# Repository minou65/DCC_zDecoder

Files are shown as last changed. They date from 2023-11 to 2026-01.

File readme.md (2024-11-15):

# DCC zDecoder

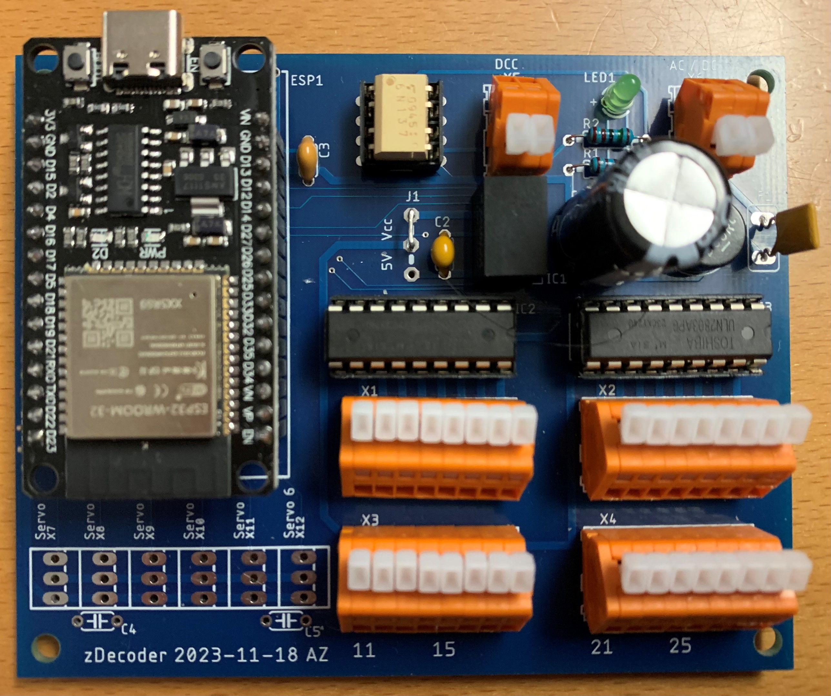
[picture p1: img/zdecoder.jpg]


- [DCC zDecoder](#dcc-zdecoder)
	- [Beschreibung](#beschreibung)
	- [Platinen](#platinen)
	- [Librarys](#librarys)
	- [Pin mapping](#pin-mapping)
	- [Betriebsarten](#betriebsarten)
		- [in Vorbereitung](#in-vorbereitung)
	- [Schema](#schema)
	- [Materialliste](#materialliste)
	- [Anschlüsse](#anschlüsse)
	- [Inbetriebnahme](#inbetriebnahme)
	- [Web UI](#web-ui)
		- [Overview](#overview)
		- [Groups](#groups)
		- [Config](#config)
	- [WiFi](#wifi)
		- [Default Password](#default-password)
		- [Default IP address](#default-ip-address)
		- [OTA](#ota)
		- [Configuration options](#configuration-options)
		- [Blinking codes](#blinking-codes)
	- [Firmware](#firmware)
	- [Reset](#reset)

## Beschreibung
Das ist ein NRMA DCC dekoder basirend auf einem ESP32 NodeMCU. 
- Er kann bis zu 16 Ausgänge ansteuern. 
- Stellt eine Wifi AP zur verfügung oder kann in Wifi Netz integriert werden
- Wird via Web UI konfiguriert
- Kann via DCC oder Web UI gesteuert werden

Der Decoder kann an einer Spannung von 8 - 28V DC oder 18 - 36V AC betrieben werden. Pro Ausgang 
kann eine Last von 500mA geschaltet werden. Ist J1 auf der Stellung 5V, darf der gesamt Strom 1A
nicht übersteigen.

[Top of document](#dcc-zdecoder)

## Platinen
Unbestückte Platinen sind bei mir erhältlich für CHF 5.00 / Stück plus Porto. Bestückte Platinen CHF 30.00 plus Porto
[Top of document](#dcc-zdecoder)

## Librarys
Die folgenden Bibliotheken werden verwendet und müssen installiert werden
- [NMRA DCC](https://github.com/mrrwa/NmraDcc)
- [IotWebConf (3.2.3)](https://github.com/minou65/IotWebConf)
- [IotWebRoot](https://github.com/minou65/IotWebRoot)

[Top of document](#dcc-zdecoder)

## Pin mapping
In der Header datei [pinmapping.h](src/pinmapping.h) können die Pins für die 16 Ausgänge an die eigenen Bedürfnisse angepasst werden.

```cpp
static uint8_t ChannelToGPIOMapping[16] = {
	GPIO_NUM_23, // O11
	GPIO_NUM_22, // O12
	GPIO_NUM_21, // O13
	GPIO_NUM_19, // O14
	GPIO_NUM_18, // O15
	GPIO_NUM_17, // O16
	GPIO_NUM_16, // O17
	GPIO_NUM_4,  // O18

	GPIO_NUM_33, // O21
	GPIO_NUM_32, // O22
	GPIO_NUM_25, // O23
	GPIO_NUM_26, // O24
	GPIO_NUM_27, // O25
	GPIO_NUM_14, // O26
	GPIO_NUM_12, // O27
	GPIO_NUM_13  // O28

};
```
[Top of document](#dcc-zdecoder)

## Betriebsarten

Der zDecoder untersützt folgende Betriebsarten
- [Watchdog](doc/watchdog.md#watchdog-1)
- [einfacher Ausgang](doc/blinkers.md#einfacher-ausgang)
- [Blinker](doc/blinkers.md#blinker)
- [Wechselblinker](doc/blinkers.md#wechselblinker)
- [Fernseher](doc/blinkers.md#fernseher)
- [Schweisslicht](doc/blinkers.md#schweissen)
- [Feuer](doc/blinkers.md#feuer)
- [Blitzlicht](doc/blinkers.md#blitzlicht)
- [Lauflicht 1](doc/blinkers.md#lauflicht-1)
- [Lauflicht 2](doc/blinkers.md#lauflicht-2)
- [Lauflicht 3](doc/blinkers.md#lauflicht-3)
- [Lauflicht 4](doc/blinkers.md#lauflicht-4)
- [Hausbeleuchtung](doc/blinkers.md#hausbeleuchtung)
- [Neonlampen](doc/blinkers.md#neon-lampe)
- [Natriumlampen](doc/blinkers.md#natrium-lampe)
- [Entkuppler](doc/coils.md#entkuppler)
- [Weiche](doc/coils.md#weiche)
- [Servo](doc/servo.md#servo-1)

[Top of document](#dcc-zdecoder)

### in Vorbereitung
- SBB Hauptsignal 2 flammig
- SBB Hauptsignal 3 flammig
- SBB Hauptsignal 4 flammig
- SBB Hauptsignal 5 flammig
- SBB Zwergsignal
- Strassensignal

[Top of document](#dcc-zdecoder)

## Schema
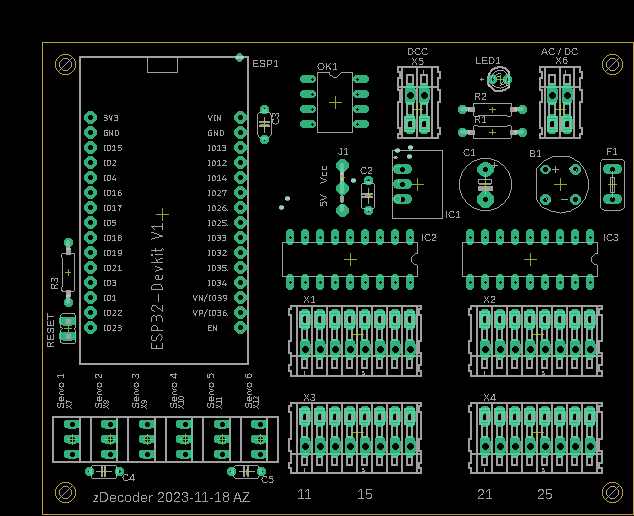
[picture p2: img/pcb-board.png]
PCB Board


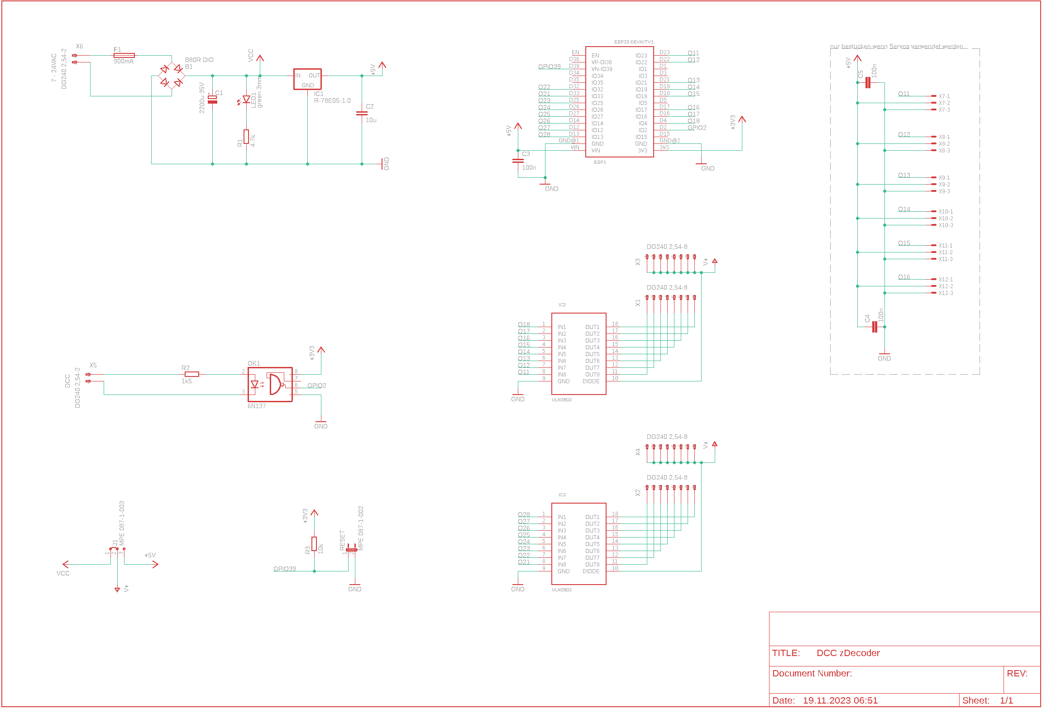
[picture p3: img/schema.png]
Schema


## Materialliste

[Partliste](sch/partlist.txt)

[Top of document](#dcc-zdecoder)

## Anschlüsse

| Klemmenblock | Beschreibung |
| --- | --- |
| X1 - X2 | + Anschluss für Verbraucher 5/12-28VDc, je nach position von J1 |
| X3 - X4 | - Anschluss für Verbraucher |
| X5 | DCC signal |
| X6 | Anschluss versorgungspannung für Decoder und Verbraucher. 12 - 28VDC/AC |
| X7 - X12 | Anschluss für Servos |

[Top of document](#dcc-zdecoder)

## Inbetriebnahme

Nachdem alles zusammengebaut ist und alle Lötstellen sorgfältig überprüft wurden, kann das Program auf den ESP aufgespielt werden.
Lauflicht 2

[Top of document](#dcc-zdecoder)

## Web UI

Mittels des Web User interfaces kann der zDecoder einfach konfiguriert und bedient werden

### Overview

auf dieser Seite sind alle wichtigen Informationn zu zDecoder ersichtlich

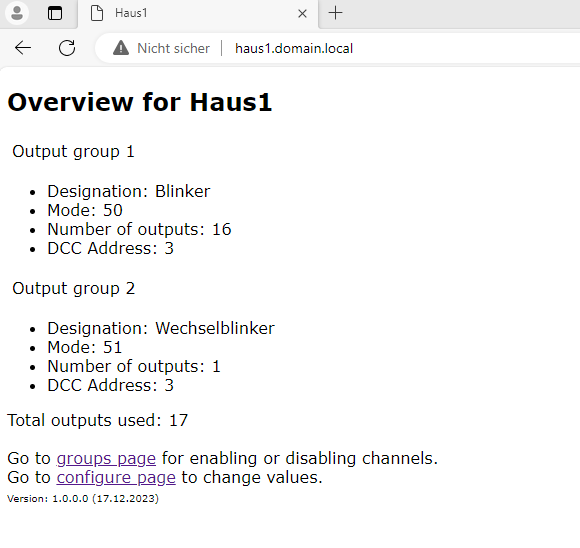
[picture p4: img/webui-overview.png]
Overview


[Top of document](#dcc-zdecoder)

### Groups

auf dieser Seite können die Gruppen ein und ausgescahltet werden. Wird über DCC geschaltet, ist auf dieser Seite auch der jeweilige Status ersichtlich. Rot ist ausgeschaltet, grün ist eingeschaltet

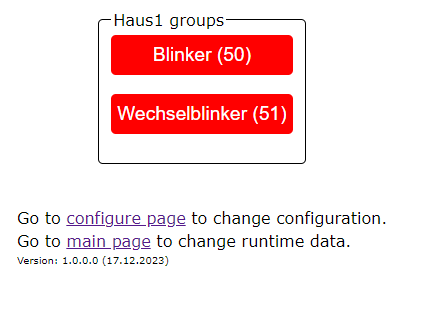
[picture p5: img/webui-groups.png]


[Top of document](#dcc-zdecoder)

### Config

auf dieser Seite können die Gruppen erstellt und konfiguriert werden. Die Bedeutung und Verwendung der Parameter ist beim jeweiligen Objekt unter [Betriebsarten](#betriebsarten) beschrieben.

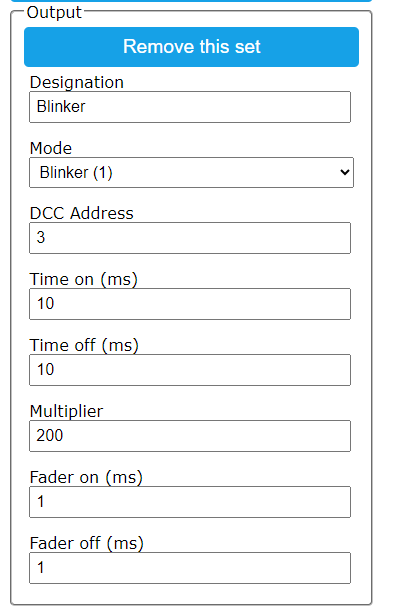
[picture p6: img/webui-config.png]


[Top of document](#dcc-zdecoder)

## WiFi

### Default Password

Wenn nicht mit einem AP verbunden, ist das Standardpasswort 123456789

[Top of document](#dcc-zdecoder)

### Default IP address

Wenn nicht mit einem AP verbunden, ist die IP Adresse 192.168.4.1

[Top of document](#dcc-zdecoder)

### OTA 
OTA ist aktiviert und kann verwenbdet werden. Damit ist es möglich, die Software des zDecoders zu updaten ohne unter die Anlage krichen zu müssen. Die IP Adresse ist entweder die Default IP address oder die vom AP zugewissene. Port ist Standart

[Top of document](#dcc-zdecoder)

### Configuration options
Nach dem ersten Start müssen einige Werte eingerichtet werden.

| Parameter | Beschreibung |
|---|---|
| Thing name | Name des Decoders. Es sollten keine Sonderzeichen und <br> Umlaute verwendet werden. Punkte und Leerzeichen sollten <br> ebenfalls nicht verwendet werden.
| AP password | Dieses Passwort wird verwendet, wenn Sie später auf <br> das Gerät zugreifen möchten. Sie müssen ein Passwort <br> mit mindestens 8, höchstens 32 Zeichen verwenden. <br> Es steht Ihnen frei, beliebige Zeichen zu verwenden, <br> Es sollte ein Passwort mit mindestens 12 Zeichen Länge gewählt werden. |
| WiFi SSID | Name des WLan mit welchem das thing verwendet werden soll. |
| WiFi password | Das Passwort zum Netzwerk, mit welchem das Thing verbunden werden soll. |

[Top of document](#dcc-zdecoder)

### Blinking codes

In der nachfolgenden Tabelle fasst die verschiedenen Blinkcodes zusammen

| Code | Bedeutung |
|---|---|
| rasches blinken | meisten ein, unterbrochen durch kurze aus perioden. <br> Eigener AP ist aktiviert und sie können mit <br> dem Smartphone oder einem Computer eine<br> Verbindung zum Thing herstellen. |
| wechsel blinken | Das Thing versucht mit einem AP zu verbinden |
| langsames blinken | meistens aus mit kurzem blinken <br> Das Thing ist online und mit dem WLan verbunden |

[Top of document](#dcc-zdecoder)

## Firmware
Hier kann, eine entsprechende Datei vorausgesetzt, die Firmware des decoders aktualisiert werden

## Reset
Wurde das Passwort vergessen oder funktioniert der Decoder nicht mehr kann durch schliessen des Jumpers Reset während dem booten, der Decoder auf die Werkseinstellungen zurückgesetzt werden.

[Top of document](#dcc-zdecoder)

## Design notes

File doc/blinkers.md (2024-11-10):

# Blinkers

## Inhalt
- [Blinkers](#blinkers)
  - [Inhalt](#inhalt)
  - [einfacher Ausgang](#einfacher-ausgang)
  - [Blinker](#blinker)
  - [Wechselblinker](#wechselblinker)
  - [Fernseher](#fernseher)
  - [Schweissen](#schweissen)
  - [Feuer](#feuer)
  - [Blitzlicht](#blitzlicht)
  - [Lauflicht 1](#lauflicht-1)
  - [Lauflicht 2](#lauflicht-2)
  - [Lauflicht 3](#lauflicht-3)
  - [Lauflicht 4](#lauflicht-4)
  - [Hausbeleuchtung](#hausbeleuchtung)
  - [Natrium Lampe](#natrium-lampe)
  - [Neon Lampe](#neon-lampe)

## einfacher Ausgang
Ein einfacher Ausgang um z.B. eine Lampe oder Relais ein und auszuschalten.

| Channel | Led Farbe | 
|:-:|---|
| 1 | n.a.  |

| Feld | Beschreibung | Wert |
| --- | --- | --- |
| Designation | Beschreibung des Channels | |
| Modus | ein/aus | einfacher Ausgang |
| Address | DCC Adresse des Ausgangs | default 3 |
| Brightness | Helligkeit des Ausgangs | default 255 |

[Betriebsarten](../readme.md#betriebsarten) <br>
[Top of document](#blinkers)

## Blinker
Einfacher blinker, welcher es erlaubt auch ein und aus zu faden

| Channel | Led Farbe |
|:-:|---|
| 1 | n.a.  |
| 2  | n.a. |

| Feld | Beschreibung | Wert |
| --- | --- | --- |
| Designation | | |
| Modus | | Blinker |
| Address | DCC Adresse des Ausgangs | default 3 |
| Blinker time on | ein in ms | |
| Blinker time off | aus in ms | |
| Multiplikator | Multiplikator mit welchem die ein / aus Zeit multipliziert wird | |
| Fade Time on | Zeit in ms für das Fade on | |
| Fade Time off | Zeit in ms für das Fade off | |
| Brightness | Helligkeit des Ausgangs | default 255 |

[Betriebsarten](../readme.md#betriebsarten) <br>
[Top of document](#blinkers)

## Wechselblinker
Wechselblinker, welcher es erlaubt auch ein und aus zu faden

| Channel | Led Farbe |
|:-:|---|
| 1 | n.a.  |
| 2  | n.a. |

| Feld | Beschreibung | Wert |
| --- | --- | --- |
| Designation | | |
| Modus | | Wechselblinker |
| Address | DCC Adresse des Ausgangs | default 3 |
| Blinker time on | ein in ms | |
| Blinker time off | aus in ms | |
| Multiplikator | Multiplikator mit welchem die ein / aus Zeit multipliziert wird | |
| Fade Time on | Zeit in ms für das Fade on | |
| Fade Time off | Zeit in ms für das Fade off | |
| Brightness | Helligkeit des Ausgangs | default 255 |

[Betriebsarten](../readme.md#betriebsarten) <br>
[Top of document](#blinkers)

## Fernseher
Simulation eines Fernsehers

| Channel | Led Farbe |
|:-:|---|
| 1 | blau  |

| Feld | Beschreibung | Wert |
| --- | --- | --- |
| Designation | | |
| Modus | | Fernseher |
| Address | DCC Adresse des Ausgangs | default 3 |
| Brightness | Helligkeit des Ausgangs | default 255 |

[Betriebsarten](../readme.md#betriebsarten) <br>
[Top of document](#blinkers)

## Schweissen
Simuliert ein Schweisslicht

| Channel | Led Farbe |
|:-:|---|
| 1 | weiss  |
| 2  |blau|
| 3  |organge|

| Feld | Beschreibung | Wert |
| --- | --- | --- |
| Designation | | |
| Modus | | Schweissen |
| Address | DCC Adresse des Ausgangs | default 3 |
| Blinker time on | minimalae Pause in ms zwischen zwei Schweiss vorgängen | |
| Blinker time off | maximale Pause in ms zwischen zwei Scheiss vorgängen  | |
| Multitiplikator | Faktor mit welchem die ein / aus Zeit mulitpliziert wird| |
| Brightness | Helligkeit des Ausgangs | default 255 |

[Betriebsarten](../readme.md#betriebsarten) <br>
[Top of document](#blinkers)

## Feuer
Simuliert ein flackerndes Feuer

| Channel | Led Farbe |
|:-:|---|
| 1 | gelb |
| 2  | rot |
| 3  | gelb |

| Feld | Beschreibung | Wert |
| --- | --- | --- |
| Designation | | |
| Modus |  |  Feuer |
| Address | DCC Adresse des Ausgangs | default 3 |
| Brightness | Helligkeit des Ausgangs | default 255 |

[Betriebsarten](../readme.md#betriebsarten) <br>
[Top of document](#blinkers)

## Blitzlicht
Simuliert einen Fotoblitz. Es wird ein Blitzlicht gewitter erzeugt und dann jeweils zwischen 5 und 30 sekunden gewartet, bis das nächste Blitzlicht Gewitter erzeugt wird
Die flashtime sollte zwischen 100 und 300 ms sein, um gute Ergebinsse zu erreichen.

| Channel | Led Farbe |
|:-:|---|
| 1 | weiss |

| Feld | Beschreibung | Wert |
| --- | --- | --- |
| Designation | | |
| Modus |  |  Blitzlicht |
| Address | DCC Adresse des Ausgangs | default 3 |
| Minimum pause time | minimale pausenzeit in milisekunden <br> wird mulitpliziert mit Multiplier | 10 |
| Maximal pause time | maximale pausenzeit in milisekunden <br> wird mulitpliziert mit Multiplier | 30 |
| Multiplier | Faktor mit welchem die min / max Pausenzeit mulitpliziert wird| 10 |
| Minimum flash time | minimale pausenzeit in sekunden | 5 |
| Maximal flash time | maximale pausenzeit in sekunden | 30 |
| Brightness | Helligkeit des Ausgangs | default 255 |

[Betriebsarten](../readme.md#betriebsarten) <br>
[Top of document](#blinkers)

## Lauflicht 1
Kette durchgehen und notwendige LED einschalten, die anderen aussschalten

| Channel | Led Farbe |
|:-:|---|
| 1 - max | n.a. |

| Feld | Beschreibung | Wert |
| --- | --- | --- |
| Designation | | |
| Modus | | Lauflicht 1 |
| Number of outputs| 1 - 16 | |
| Address | DCC Adresse des Ausgangs | default 3 |
| Blinker time on | | |
| Blinker time off | | |
| Einheit | | |
| Brightness | Helligkeit des Ausgangs | default 255 |

[Betriebsarten](../readme.md#betriebsarten) <br>
[Top of document](#blinkers)

## Lauflicht 2
Alle Lampen werden nacheinander eingschaltet, am Schluss werden alle ausgeschaltet

| Channel | Led Farbe |
|:-:|---|
| 1 - max | n.a. |

| Feld | Beschreibung | Wert |
| --- | --- | --- |
| Designation | | |
| Modus | | Lauflicht 2 |
| Number of outputs| 1 - 16 | |
| Address | DCC Adresse des Ausgangs | default 3 |
| Blinker time on | | |
| Blinker time off | | |
| Einheit | | |
| Brightness | Helligkeit des Ausgangs | default 255 |

[Betriebsarten](../readme.md#betriebsarten) <br>
[Top of document](#blinkers)

## Lauflicht 3
Lampe für Lampe wird eingeschaltet. Sind alle eingeschaltet, wird mit der ersten Lampe begonnen zu löschen.

| Channel | Led Farbe |
|:-:|---|
| 1 - max | n.a. |

| Feld | Beschreibung | Wert |
| --- | --- | --- |
| Designation | | |
| Modus | | Lauflicht 3 |
| Number of outputs| 1 - 16 | |
| Address | DCC Adresse des Ausgangs | default 3 |
| Blinker time on | | |
| Blinker time off | | |
| Einheit | | |
| Brightness | Helligkeit des Ausgangs | default 255 |

[Betriebsarten](../readme.md#betriebsarten) <br>
[Top of document](#blinkers)

## Lauflicht 4
Funktion analaog Lauflicht 1, aber in beide richtungen (Knigth rider)

| Channel | Led Farbe |
|:-:|---|
| 1 - max | n.a. |

| Feld | Beschreibung | Wert |
| --- | --- | --- |
| Designation | | |
| Modus | | |
| Modus | | Lauflicht 4 |
| Number of outputs| 1 - 16 | |
| Address | DCC Adresse des Ausgangs | default 3 |
| Blinker time on | | |
| Blinker time off | | |
| Einheit | | |
| Brightness | Helligkeit des Ausgangs | default 255 |

[Betriebsarten](../readme.md#betriebsarten) <br>
[Top of document](#blinkers)

## Hausbeleuchtung

| Channel | Led Farbe |
|:-:|---|
| 1 - max | n.a. |

| Feld | Beschreibung | Wert |
| --- | --- | --- |
| Designation | | |
| Modus | | Hausbleuchtung |
| Number of outputs| 1 - 16 | |
| Address | DCC Adresse des Ausgangs | default 3 |
| Blinker time on | | |
| Blinker time off | | |
| Einheit | | |
| Brightness | Helligkeit des Ausgangs | default 255 |

[Betriebsarten](../readme.md#betriebsarten) <br>
[Top of document](#blinkers)

## Natrium Lampe
Simuliert eine oder mehere Natriumlampen. Beim einschalten beginnt die lampe zu glühen um dann den Betriebsdruck aufzubauen und voll zu leuchten. In dieser Zeit leuchtet die LED immer heller. Beim ausschalten glüht die Lampe aus um nach einer bestimmten Zeit komplett dunckel zu sein. Über die Zahl chance wird bestimmt ob es allenfalls ein defekte Lampe gibt. Es wird jweils gewürfelt, welche Lampe defekt ist.

| Channel | Led Farbe |
|:-:|---|
| 1 - max | gelb |

| Feld | Beschreibung | Wert |
| --- | --- | --- |
| Designation | | |
| Modus | | Natriumlampen |
| Number of outputs| 1 - 16 | |
| Address | DCC Adresse des Ausgangs | default 3 ||
| Mulitiplier | Prozentuale chance auf defekte Lampe: <br/> für 50:50 den Wert 1. <br/> für 33:66 den Wert 2, etc. <br/> wenn Null dann gibt es keine defekte Lampe <br/> wenn 255, dann gibt es immer eine defekte Lampe | |
| Fade Time on | minimale Zeit für Glühen| |
| Fade Time off | maximale Zeit für Glühen | |
| Brightness | Helligkeit des Ausgangs | default 255 |

[Betriebsarten](../readme.md#betriebsarten) <br>
[Top of document](#blinkers)

## Neon Lampe
Simuliert eine oder mehere Nenolampen. Beim einschalten blinken die Lampen 1-5 mal. Je nach Anzahl Lampen und einstellung der Chance kommt es immer mal vor das eis eine defekte Lampe gibt. Diese wird dann dauerhaft versuchen einzuschalten.

| Channel | Led Farbe |
|:-:|---|
| 1 - max | weiss |

| Feld | Beschreibung | Wert |
| --- | --- | --- |
| Designation | | |
| Modus | | Neonlampen |
| Number of outputs| 1 - 16 | |
| Address | DCC Adresse des Ausgangs | default 3 |
| Mulitiplier | Prozentuale chance auf defekte Lampe: <br/> für 50:50 den Wert 1. <br/> für 33:66 den Wert 2, etc. <br/> wenn Null dann gibt es keine defekte Lampe <br/> wenn 255, dann gibt es immer eine defekte Lampe | |
| Brightness | Helligkeit des Ausgangs | default 255 |

[Betriebsarten](../readme.md#betriebsarten) <br>
[Top of document](#blinkers)

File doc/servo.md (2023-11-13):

# Servo

- [Servo](#servo)
  - [Servo](#servo-1)

## Servo
Dies ist ein Servo Ausgang. Er wird mittels einer Weichenadresse angesteuert

| Feld | Beschreibung | Wert |
| --- | --- | --- |
| Designation | Beschreibung des Servos | |
| Address | DCC Adresse des Servos. | default 3 |
| Travel time | Zeit in ms die der Server verwendet um vom Limit 1 (2) nach Limit 2 (1) zu bewegen | default 10 |
| Multiplier | Multiplikator mit welchem die Zeit multipliziert wird | default 10 |
| Limit 1 | Limite 1 in °. Es können Werte zwischen 0 und 180 eingestellt werden | default 0 |
| Limit 2 | Limite 2 in °. Es können Werte zwischen 0 und 180 eingestellt werden | default 180 |

[Betriebsarten](../readme.md#betriebsarten) <br>
[Top of document](#servo)

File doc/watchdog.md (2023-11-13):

# Watchdog

## Inhalt

- [Watchdog](#watchdog)
  - [Inhalt](#inhalt)
  - [Watchdog](#watchdog-1)

## Watchdog
Mit dem Watchdog kann überprüft werden ob innheralb einer bestimmten Zeit DCC Signale empfangen werden

| Channel | Led Farbe | 
|:-:|---|
| 1 | keine  |

| Feld | Beschreibung | Wert |
| --- | --- | --- |
| Designation | Beschreibung des Channels | |
| Modus |  | einfacher Ausgang |
| Address | DCC Adresse des Ausgangs | default 3 |
| Blinker time on | Zeit in ms in der ein DCC Signal empfangen werden musss | |
| Multiplikator | Multiplikator mit welchem die ein Zeit multipliziert wird | |

[Betriebsarten](../readme.md#betriebsarten) <br>
[Top of document](#watchdog)

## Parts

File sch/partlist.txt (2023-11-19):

Partlist

Exported from DCC zDecoder.brd at 19.11.2023 06:50

EAGLE Version 9.6.2 Copyright (c) 1988-2020 Autodesk, Inc.

Assembly variant: 

Part     Value          Package        Library     Position (mm)         Orientation

B1       B80R DIO       RB1A           rectifier   (87.63 55.88)         R0
C1       2200u 35V      E5-8,5         rcl         (74.93 55.88)         R270
C2       10u            C050-024X044   rcl         (55.118 53.975)       R90
C3       100n           C050-024X044   rcl         (37.592 66.04)        R270
C4       100n           C050-024X044   rcl         (10.414 7.239)        R0
C5       100n           C050-024X044   rcl         (34.544 7.239)        R0
ESP1     ESP32DEVKITV1  ESP32-DEVKITV1 _esp32      (20.32 50.8)          R270
F1       900mA          TE5            fuse        (96.52 55.88)         R270
IC1      R-78E05-1.0    R-78E-XX1.0    _eigene     (63.5 55.88)          R270
IC2      ULN2803        DIL18          _eigene     (52.07 43.18)         R180
IC3      ULN2803        DIL18          _eigene     (82.55 43.18)         R180
J1       MPE 087-1-003  04C            jumper      (50.8 57.15)          R270
LED1     green 3mm      LED3MM         led         (77.47 73.66)         R0
OK1      6N137          DIL08          optocoupler (49.53 69.85)         R270
R1       4.7k           0207/10        rcl         (76.2 64.77)          R0
R2       1k5            0207/10        rcl         (76.2 68.58)          R0
R3       10k            0207/10        rcl         (4.318 41.021)        R90
RESET    MPE 087-1-002  JP1            jumper      (4.318 31.496)        R180
X1       DG240 2,54-8   233-508        con-wago255 (53.34 30.48)         R0
X2       DG240 2,54-8   233-508        con-wago255 (83.82 30.48)         R0
X3       DG240 2,54-8   233-508        con-wago255 (53.34 13.97)         R0
X4       DG240 2,54-8   233-508        con-wago255 (83.82 13.97)         R0
X5       DG240 2,54-2   233-202        con-wago255 (63.5 68.58)          R180
X6       DG240 2,54-2   233-202        con-wago255 (87.63 68.58)         R180
X7       PSS 254/3G     22-23-2031     con-molex   (5.08 12.7)           R270
X8       PSS 254/3G     22-23-2031     con-molex   (11.43 12.7)          R270
X9       PSS 254/3G     22-23-2031     con-molex   (17.78 12.7)          R270
X10      PSS 254/3G     22-23-2031     con-molex   (24.13 12.7)          R270
X11      PSS 254/3G     22-23-2031     con-molex   (30.48 12.7)          R270
X12      PSS 254/3G     22-23-2031     con-molex   (36.83 12.7)          R270

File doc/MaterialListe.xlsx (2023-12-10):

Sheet: Tabelle1
PCB |  | PCBParts | CHF 3.50 | Bei Bestellung von 20Stk
ESP1 | ESP32 NodeMCU | ebay | CHF 4.70
IC1 | 6N137 | ebay | CHF 0.15
IC2 | ULN2803 | ebay | CHF 0.40
IC3 | ULN2803 | ebay | CHF 0.40
IC4 | DC/DC Wandler TSR 1-2450 | Reichelt | CHF 5.20
R1 |  |  | CHF 0.05
R2 |  |  | CHF 0.05
C1 |  |  | CHF 1.00
LED1 |  |  | CHF 0.05
B1 | B80R DIO | Reichelt | CHF 0.30
J1 |  |  | CHF 0.10
X1 | DG240 2,54-8 | Reichelt | CHF 1.60
X2 | DG240 2,54-8 | Reichelt | CHF 1.60
X3 | DG240 2,54-8 | Reichelt | CHF 1.60
X4 | DG240 2,54-8 | Reichelt | CHF 1.60
X5 | DG240 2,54-2 | Reichelt | CHF 0.50
X6 | DG240 2,54-2 | Reichelt | CHF 0.50
IC Sockel | GS 8 | Reichelt | CHF 0.05
IC Sockel | GS 16 | Reichelt | CHF 0.10
IC Sockel | GS 16 | Reichelt | CHF 0.10
Buchsenleiste |  | Reichelt | CHF 2.00
 | Total |  | CHF 25.55
 | Preis pro Ausgang |  | CHF 1.60
 | ohne Servoausgänge bestückt

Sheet: Kosten
Bauteil | Bestellnummer | Lieferant
Printplatte |  | PCB | CHF 4.50
F1 | U90 XEAA | ebay | CHF 0.20
B1 | B80R DIO | reichelt | CHF 0.30
C1 | 2200u 35V | ebay | CHF 1.00
C2 | 10u MLCC | ebay | CHF 0.10
C3 | 100n MLCC | ebay | CHF 0.10
ESP1 | ESP32 NodeMCU | ebay | CHF 4.70
IC1 | TSR 1-2450 | reichelt | CHF 5.20
IC2 | ULN2803 | ebay | CHF 0.40
IC3 | ULN2803 | ebay | CHF 0.40
J1 | MPE 087-1-003 | ebay | CHF 0.10
LED1 | green 3mm | ebay | CHF 0.15
OK1 | 6N137 | ebay | CHF 0.30
R1 | 4.7k | ebay | CHF 0.10
R2 | 1k5 | ebay | CHF 0.10
R3 | 10k | ebay | CHF 0.10
RESET | MPE 087-1-002 | ebay | CHF 0.10
X1 | DG240 2,54-8 | reichelt | CHF 1.40
X2 | DG240 2,54-8 | reichelt | CHF 1.40
X3 | DG240 2,54-8 | reichelt | CHF 1.40
X4 | DG240 2,54-8 | reichelt | CHF 1.40
X5 | DG240 2,54-2 | reichelt | CHF 0.50
X6 | DG240 2,54-2 | reichelt | CHF 0.50
IC Sockel | GS 8 | Reichelt | CHF 0.05
IC Sockel | GS 18 | Reichelt | CHF 0.10
IC Sockel | GS 18 | Reichelt | CHF 0.10
Buchsenleiste |  | Reichelt | CHF 2.00
 |  |  | CHF 26.70

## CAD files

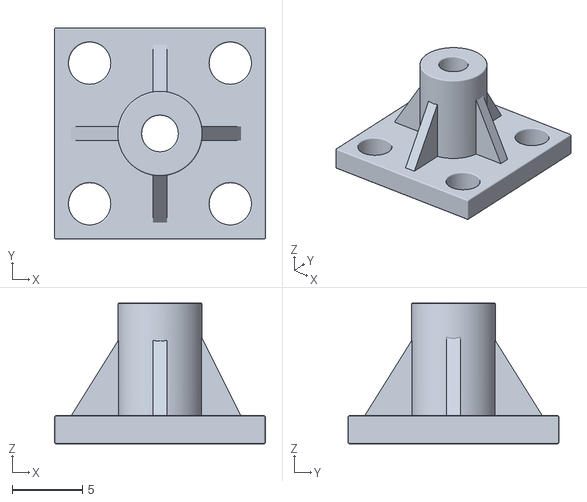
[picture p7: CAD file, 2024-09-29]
stl/PCB-Support.stl
15.0 x 15.0 x 10.0

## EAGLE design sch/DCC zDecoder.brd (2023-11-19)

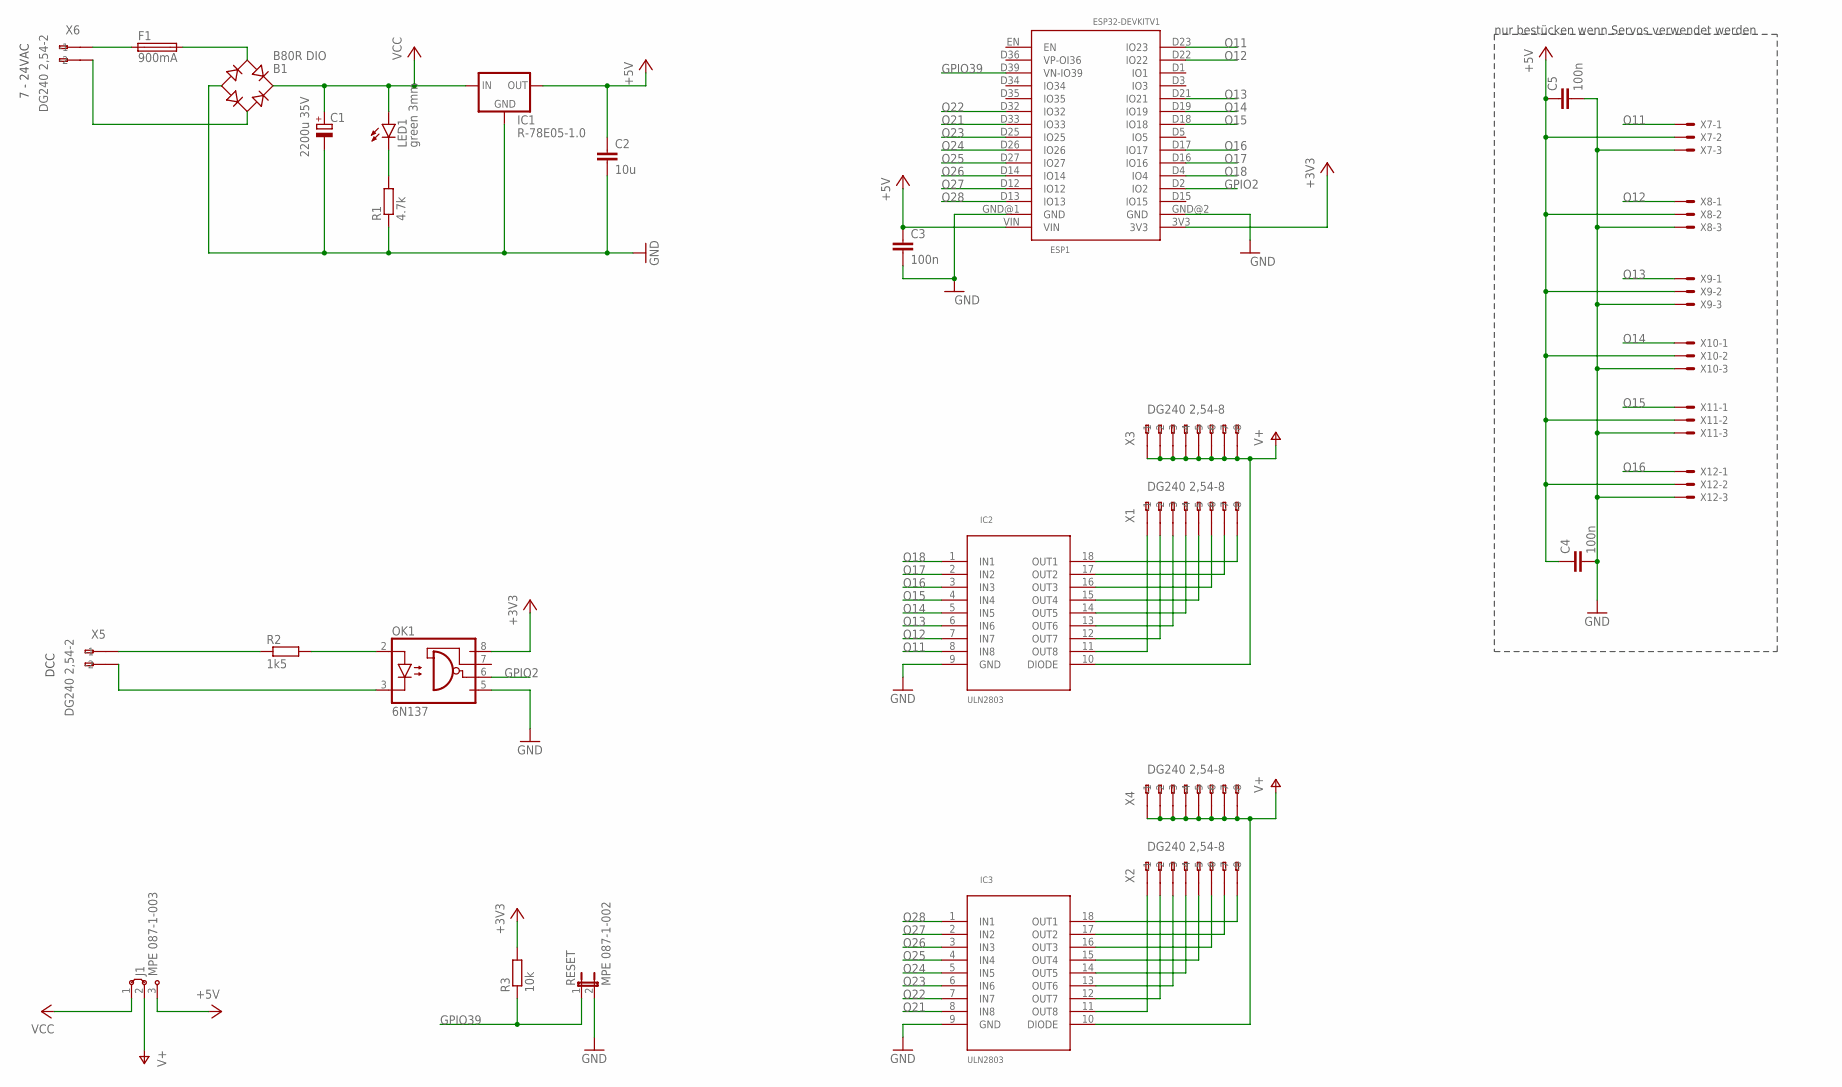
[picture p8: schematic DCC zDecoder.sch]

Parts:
B1: B80R DIO; RB1A
C1: 2200u 35V; E5-8,5
C2: 10u; C050-024X044
C3, C4, C5: 100n; C050-024X044
ESP1: ESP32DEVKITV1; ESP32-DEVKITV1
F1: 900mA; TE5
IC1: R-78E05-1.0; R-78E-XX1.0
IC2, IC3: ULN2803; DIL18
J1: MPE 087-1-003; 04C
LED1: green 3mm; LED3MM
OK1: 6N137; DIL08
R1: 4.7k; 0207/10
R2: 1k5; 0207/10
R3: 10k; 0207/10
RESET: MPE 087-1-002; JP1
X1, X2, X3, X4: DG240 2,54-8; 233-508
X5, X6: DG240 2,54-2; 233-202
X7, X8, X9, X10, X11, X12: PSS 254/3G; 22-23-2031

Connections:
+3V3: ESP1.3V3, OK1.8 (VCC), R3.2
+5V: C2.1, C3.1, C4.1, C5.1, ESP1.VIN, IC1.OUT, J1.3, X7.2, X8.2, X9.2, X10.2, X11.2, X12.2
GND: B1.-, C1.-, C2.2, C3.2, C4.2, C5.2, ESP1.GND@1 (GND), ESP1.GND@2 (GND), IC1.GND, IC2.9 (GND), IC3.9 (GND), OK1.5 (GND), R1.1, RESET.2, X7.3, X8.3, X9.3, X10.3, X11.3, X12.3
GPIO2: ESP1.D2 (IO2), OK1.6 (VO)
GPIO39: ESP1.D39 (VN-IO39), R3.1, RESET.1
unnamed: IC2.11 (OUT8), X1.A1 (-1)
unnamed: IC2.12 (OUT7), X1.A2 (-2)
unnamed: LED1.K (C), R1.2
unnamed: IC2.13 (OUT6), X1.A3 (-3)
unnamed: B1.AC1, F1.2
unnamed: B1.AC2, X6.A2 (-2)
unnamed: IC2.14 (OUT5), X1.A4 (-4)
unnamed: IC2.15 (OUT4), X1.A5 (-5)
unnamed: R2.1, X5.A1 (-1)
unnamed: OK1.2 (A), R2.2
unnamed: OK1.3 (C), X5.A2 (-2)
unnamed: IC2.16 (OUT3), X1.A6 (-6)
unnamed: IC2.17 (OUT2), X1.A7 (-7)
unnamed: IC2.18 (OUT1), X1.A8 (-8)
unnamed: F1.1, X6.A1 (-1)
unnamed: IC3.18 (OUT1), X2.A8 (-8)
unnamed: IC3.17 (OUT2), X2.A7 (-7)
unnamed: IC3.16 (OUT3), X2.A6 (-6)
unnamed: IC3.15 (OUT4), X2.A5 (-5)
unnamed: IC3.14 (OUT5), X2.A4 (-4)
unnamed: IC3.13 (OUT6), X2.A3 (-3)
unnamed: IC3.12 (OUT7), X2.A2 (-2)
unnamed: IC3.11 (OUT8), X2.A1 (-1)
O11: ESP1.D23 (IO23), IC2.8 (IN8), X7.1
O12: ESP1.D22 (IO22), IC2.7 (IN7), X8.1
O13: ESP1.D21 (IO21), IC2.6 (IN6), X9.1
O14: ESP1.D19 (IO19), IC2.5 (IN5), X10.1
O15: ESP1.D18 (IO18), IC2.4 (IN4), X11.1
O16: ESP1.D17 (IO17), IC2.3 (IN3), X12.1
O17: ESP1.D16 (IO16), IC2.2 (IN2)
O18: ESP1.D4 (IO4), IC2.1 (IN1)
O21: ESP1.D33 (IO33), IC3.8 (IN8)
O22: ESP1.D32 (IO32), IC3.7 (IN7)
O23: ESP1.D25 (IO25), IC3.6 (IN6)
O24: ESP1.D26 (IO26), IC3.5 (IN5)
O25: ESP1.D27 (IO27), IC3.4 (IN4)
O26: ESP1.D14 (IO14), IC3.3 (IN3)
O27: ESP1.D12 (IO12), IC3.2 (IN2)
O28: ESP1.D13 (IO13), IC3.1 (IN1)
V+: IC2.10 (DIODE), IC3.10 (DIODE), J1.2, X3.A1 (-1), X3.A2 (-2), X3.A3 (-3), X3.A4 (-4), X3.A5 (-5), X3.A6 (-6), X3.A7 (-7), X3.A8 (-8), X4.A1 (-1), X4.A2 (-2), X4.A3 (-3), X4.A4 (-4), X4.A5 (-5), X4.A6 (-6), X4.A7 (-7), X4.A8 (-8)
VCC: B1.+, C1.+, IC1.IN, J1.1, LED1.A

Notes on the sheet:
7 - 24VAC
DCC
nur bestücken wenn Servos verwendet werden

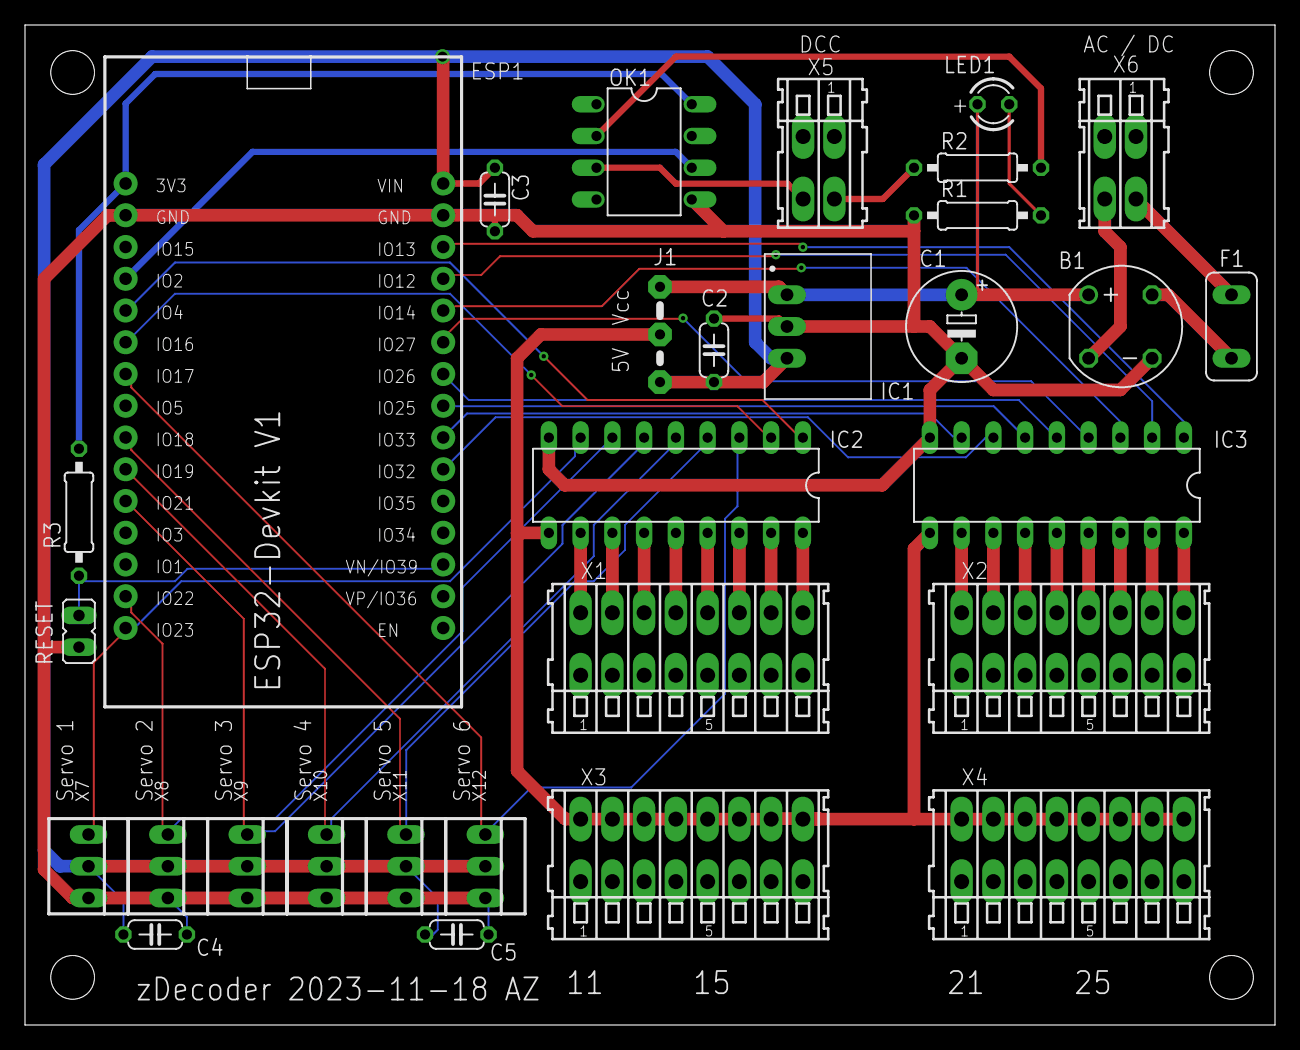
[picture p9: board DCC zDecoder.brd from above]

Board: 2 copper layers, 100.0 x 80.0 mm, 30 parts (0 on the bottom side), 46 nets.

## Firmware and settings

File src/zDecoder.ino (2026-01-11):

/*
 Name:		zDecoder.ino
 Created:	14.10.2023 10:58:37
 Author:	andy
*/

#define IOTWEBCONFASYNC_DEBUG_TO_SERIAL 1

#include <Arduino.h>

#include "version.h"
#include "pinmapping.h"

#include "webhandling.h"

#include "ESP32_DecoderCore.h"

char Version[] = VERSION_STR;

// Task handle (Core 0 on ESP32)
TaskHandle_t TaskHandle;

bool ResetDCCDecoder = false;


void zDecoderReset() {
	OutputGroup* outputgroup_ = &OutputGroup1;
	while (outputgroup_ != nullptr) {
		outputgroup_->applyDefaultValues();
		outputgroup_->setActive(false);

		outputgroup_ = (OutputGroup*)outputgroup_->getNext();
	}
}

void zDecoderInit(void) {
	decoder.reset(); // Clear the decoder list	

	Serial.println("======== Setting up outputs... =========");
	uint8_t OutputIndex_ = 0;
	uint8_t totalAssignedPins_ = 0;
	OutputGroup* outputgroup_ = &OutputGroup1;
	while (outputgroup_ != nullptr) {
		if (ESP32PWM::PWMCount > NUM_PWM) {
			Serial.print("No more pwm channels available for servos! max: "); Serial.println(NUM_PWM);
			break;
		}

		if (OutputIndex_ >= MAX_OUTPUT_PINS) {
			Serial.println("No more output pins available!");
			break;
		}

		if (outputgroup_->isActive()) {
			// Read parameters
			uint8_t Mode_ = outputgroup_->getMode();
			uint8_t assignedPins_ = outputgroup_->getNumber();
			uint16_t Address_ = outputgroup_->getAddress();
			uint16_t TimeOn_ = outputgroup_->getTimeOn();
			uint16_t TimeOff_ = outputgroup_->getTimeOff();
			uint16_t Multiplier_ = outputgroup_->getMultiplier();
			uint16_t TimeOnFade_ = outputgroup_->getTimeOnFade();
			uint16_t TimeOffFade_ = outputgroup_->getTimeOffFade();
			uint8_t Brightness_ = outputgroup_->getBrightness();

			Serial.printf("Values for output index %u loaded\n", OutputIndex_);
			Serial.printf("    Pins assigned to this output group:: %u\n", assignedPins_);
			Serial.printf("    Address: %u\n", Address_);
			Serial.print(F("    Mode: ")); Serial.println(Mode_);

			Accessory* newAccessory_ = nullptr;

			// Prüfen auf Servomode
			if (Mode_ == 190 || Mode_ == 191 || Mode_ == 192 || Mode_ == 193) {
				// Beispiel: ServoAccessory-Konstruktor anpassen, falls andere Parameter benötigt werden
				// Accessory* createServoAccessory(uint16_t Mode, uint16_t Address, uint8_t ServoPort, uint16_t limit1, uint16_t limit2, uint16_t travelTime, uint16_t timeOn, uint16_t timeOff)
				newAccessory_ = createServoAccessory(Mode_, Address_, OutputIndex_, TimeOnFade_, TimeOffFade_, Multiplier_, TimeOn_, TimeOff_);
			}
			else {
				// Standard-Accessory
				newAccessory_ = createOutputAccessory(Mode_, Address_, OutputIndex_, assignedPins_, TimeOn_, TimeOff_, Multiplier_, TimeOnFade_, TimeOffFade_);
			}

			if (newAccessory_ != nullptr) {
				OutputIndex_ += newAccessory_->getUsedPins(); // Increase OutputIndex_ by the number of used pins

				// Set brightness if it's a LED accessory (before wrapping in SoundAccessory)
				if (newAccessory_->getType() == AccessoryType::LED) {
					Ausgang* ledAccessory = static_cast<Ausgang*>(newAccessory_);
					ledAccessory->SetMaxBrightness(Brightness_);
				}

				// add a input accessory if the output group has an input pin
				if (outputgroup_->getInputPin() > 0) {
					Serial.print("Adding input accessory for input pin: "); Serial.println(outputgroup_->getInputPin() - 1);
					Serial.print("    with active duration: "); Serial.println(outputgroup_->getActiveDuration());
					Serial.print("    and edge type: "); Serial.println(outputgroup_->getEdgeType());	
					InputAccessory* inputAccessory_ = createInputAccessory(
						outputgroup_->getInputPin() - 1,
						newAccessory_,
						outputgroup_->getActiveDuration(),
						static_cast<InputAccessory::EdgeType>(outputgroup_->getEdgeType())
					);
					decoder.add(inputAccessory_);
				}

				decoder.add(newAccessory_);
			}
			totalAssignedPins_ += assignedPins_;

			Serial.println(F("*****************************"));
		}

		outputgroup_ = (OutputGroup*)outputgroup_->getNext();
	}

	Serial.print("Decoder size: "); Serial.println(decoder.getSize());
	Serial.print("Total assigned outputs: "); Serial.println(totalAssignedPins_);
	Serial.print("Total assigned PWM channels: "); Serial.println(ESP32PWM::PWMCount);


	Serial.println(F("======== zdecoder initialization complete ========="));

}

void setup() {
	Serial.begin(115200);
	while (!Serial) {
		delay(10);
	}

	Serial.println("Starting with Firmware " + String(VERSION));

	// Allow allocation of all timers
	ESP32PWM::allocateTimer(0);
	ESP32PWM::allocateTimer(1);
	ESP32PWM::allocateTimer(2);
	ESP32PWM::allocateTimer(3);

	NMRAsetup();
	websetup();

	if (CONFIG_PIN >= 0) {
		pinMode(CONFIG_PIN, INPUT_PULLUP);
		if (digitalRead(CONFIG_PIN) == LOW) {
			Serial.println("config pin was pressed, reset decoder");
			zDecoderReset();
		}
	}
    zDecoderInit();
	Serial.println("Decoder initalized");

	xTaskCreatePinnedToCore(
		loop2, /* Function to implement the task */
		"TaskHandle", /* Name of the task */
		10000,  /* Stack size in words */
		NULL,  /* Task input parameter */
		0,  /* Priority of the task */
		&TaskHandle,  /* Task handle. */
		0 /* Core where the task should run */
	);
	Serial.println("Everything has been initialized");
}

void loop() {
	NMRAloop();
	webloop();
}

void loop2(void* parameter) {

	for (;;) {   // Endless loop
		if (ResetDCCDecoder) {
			zDecoderInit();
			ResetDCCDecoder = false;
		}

		decoder.process(); // Process all decoder accessories
		vTaskDelay(10 / portTICK_PERIOD_MS); // Delay to prevent watchdog timeout
	}
}

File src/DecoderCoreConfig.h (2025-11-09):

// DecoderCoreConfig.h

#ifndef _DecoderCoreConfig_h
#define _DecoderCoreConfig_h

#if defined(ARDUINO) && ARDUINO >= 100
	#include "arduino.h"
#else
	#include "WProgram.h"
#endif


#define SOUND_FEATURE 0 // 0 = Sound disabled, 1 = Sound enabled
#define INPUT_PIN_FEATURE 1 // 0 = Input pin disabled, 1 = Input pin enabled


#define TRAFFIC_SIGNAL_FEATURE 0 // 0 = Traffic signal disabled, 1 = Traffic signal enabled

#define NRMA_DCC_FEATURE 1 // 0 = NMRA disabled, 1 = NMRA enabled

#endif

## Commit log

2023-10-27 initial version
    [DCC zDecoder.brd, DCC zDecoder.sch]
2023-10-27 led2 and led3 should be on
2023-10-27 added values
    [DCC zDecoder.brd, DCC zDecoder.sch]
2023-10-28 updated list
    [MaterialListe.xlsx]
2023-10-29 addes support for servo
2023-10-29 PWMFrequency changed
2023-11-01 reset pin changed
2023-11-02 config pin added
2023-11-04 reset pin added and pin mapping changed
    [DCC zDecoder.brd, DCC zDecoder.sch]
2023-11-04 config pin config mouved to common.h
2023-11-05 support for servos added
2023-11-06 included servo lib as ESPServo in project
2023-11-09 added servogroup reset and set group inactive
    [zDecoder.ino]
2023-11-11 partlist updated
    [DCC zDecoder.brd, DCC zDecoder.sch]
2023-11-18 routing changed and fuse added
    [DCC zDecoder.brd, DCC zDecoder.sch]
2023-11-18 list updated
    [MaterialListe.xlsx]
2023-11-19 Version 1.0
    [DCC zDecoder.brd, DCC zDecoder.sch]
2023-12-10 IC Sockel geändert
    [MaterialListe.xlsx]
2023-12-10 Materialliste hinzugrfügt
2023-12-10 Outputs an PCB angepasst
2023-12-16 pin mapping
2023-12-17 removed notifyDccMsg and some typos fixed
    [zDecoder.ino]
2024-10-01 migratet to new version ESPAsyncWebServer. Added some error handling for more stability
    [html.h, webhandling.cpp]
2024-11-09 Add brightness control to LED class
2024-11-09 Refactor LED class member variables for clarity and consistency
2024-11-09 Refactor LEDFader and Neon classes for improved variable naming consistency
2024-11-10 Refactor LED class to inherit from accessories and implement getType method
2024-11-10 Refactor ServoControl class to inherit from accessories and implement getType method
2024-11-10 Add brightness handling for LED accessories in zDecoderInit function
2024-11-10 Refactor status indicator pin definitions for clarity and consistency
2024-11-10 Add debug print statement to getType method in Accessory class
2024-11-10 Refactor accessory classes to inherit from LEDaccessories and add SetMaxBrightness method
2024-11-10 Add LEDaccessories class with SetMaxBrightness method and refactor LED class
2024-11-10 Fix LED accessory type check and update brightness setting logic
    [zDecoder.ino]
2024-11-10 fixed form id and button id to be unique
    [html.h]
2024-11-10 fixed bug where button assigment to decodergroups was not correct
    [webhandling.cpp, zDecoder.ino]
2024-11-11 Refactor status pin handling and update ON_LEVEL definition
2024-11-15 Add handling for missing AP password and unconfigured SSID pages
    [webhandling.cpp]
2024-11-15 Add reset functionality to web handling with AJAX support
    [webhandling.cpp]
2024-11-15 Refactor LED accessory handling in zDecoderInit to remove redundant type check
2024-11-17 Fix string concatenation in updateData function for consistent formatting
    [html.h]
2024-12-18 Refactor ESPServo class to update LEDC channel attachment methods
2024-12-18 Refactor LED class to update LEDC channel attachment methods
2024-12-18 Refactor Turnout and TurnoutServo classes to use F() macro for string literals in Serial prints
2025-05-30 Add convertSettings function to configure ArduinoOTA hostname
2025-07-31 Refactor: moved to ESP32-DecoderCore
2025-08-07 Refactor: update HTML button elements for consistency and improved styling
2025-08-07 Add PinGroup enum and getPinFromIndex function for pin retrieval
2025-08-07 Refactor: removed ServoGroup tand update parameter handling
2025-08-07 Refactor: streamline zDecoder.ino by removing unused code switching to ESP32_DecoderCore lib
2025-08-25 Refactor: enhance accessory creation logic to support servo modes
2025-11-03 fix: update AsyncWebRequestWrapper initialization to include buffer size parameter
    [webhandling.cpp]
2025-11-08 Refactor: correct comments and adjust input pin values in common.h
2025-11-08 Refactor: uncomment Input Pin and Edge Type parameters in OutputGroup
2026-01-24 fix: refactor handlePost to iterate through all OutputGroups for on/off commands
    [webhandling.cpp]
